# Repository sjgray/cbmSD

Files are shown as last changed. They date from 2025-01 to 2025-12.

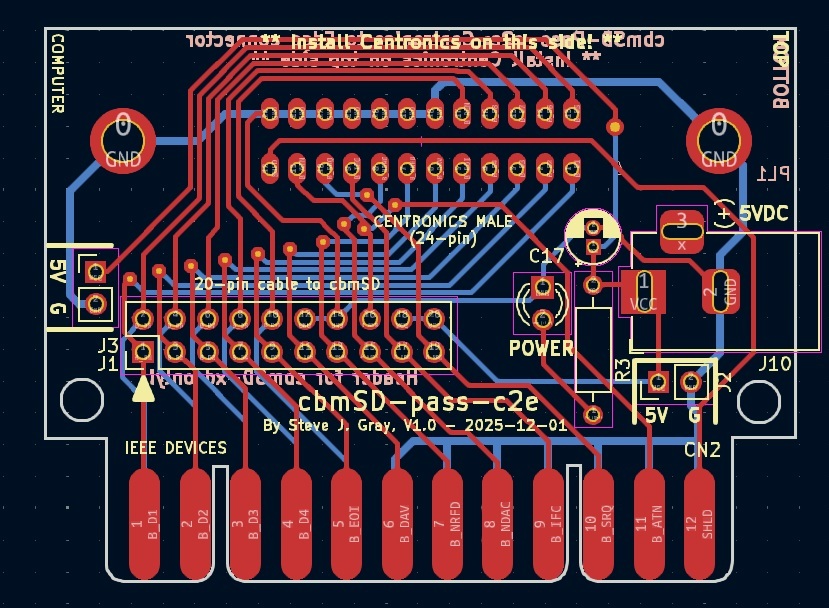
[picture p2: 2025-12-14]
passthru/pass-c2e/Pics/2025-12-01-Routed.jpg

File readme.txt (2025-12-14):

cbmSD family of SD Card Drives for Commodore Computers with IEEE
================================================================

The goal of this project is to create free open-source disk drive
solutions that are easy to build using all thru-hole parts plus
the use of a common inexpensive SD card module.

There are several variations depending on your usage:

1) cbmSD  (In development)
           A full solution providing both IEEE and IEC ports.
           For use on PET/CBM and most Commodore 8-bit machines.
           Direct-plug for IEEE but can connect to IEC devices
           with standard IEC cable.

2) cbmSD-mini
           Direct-plug solutions for PET/CBM machines with IEEE.
           With IEEE pass-thru.

3) cbmSD-xd
           Proprietary cable solution for PET/CBM machines.
           Several Pass-thru boards connect to back of computer, with ribbon cable to SD card board.
           No expensive IEEE cable required.

You will need a simple cassette port power plug or you can
power it with a standard 5V adapter with barrel jack.

Project Page
------------

http://www.cbmsteve.ca/cbmsd/index.html

Status
------

DEVICE     VER   DATE       STATUS

cbmSD      -     -          In development. Requires firmware changes
cbmSD-mini 1.2   2024-02-21 Working
cbmSD-mini 1.2v  2024-07-30 Working. Vertical mounting option.
cbmSD-xd   1.0   2024-11-18 Working. Requires cbmSD-pass board.
pass-e2e   1.0   2024-11-18 Working. Edge-2-Edge
pass-e2c   1.0   1014-11-22 Working. Edge-2-Centronics female
pass-c2e   1.0   2025-12-01 Untested. Centronics-2-Edge

Steve
2025-12-14

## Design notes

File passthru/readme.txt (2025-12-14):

cbmSD-pass - Pass-thru board for cbmSD-xd
=========================================

**NEW** Webpage: http://cbmsteve.ca/cbmsd/index.html

These pass-thru boards plug into the back of the PET/CBM and
connects to power (via cassette port or power adapter).
The "XD" connector combines the power and IEEE signals into one
proprietary pinout for convenient connection to the cbmSD-xd
board using a simple 20-pin ribbon cable. Note: That the IEEE
standard is a 24-pin connector. The GROUND pins have been
consolidated and 5V pins have been added.

You will need a simple cassette port power plug or you can
power it with a standard 5V adapter with barrel jack.

There are three versions available:

1) "E2E" - Edge-2-Edge. Edge connector output. Horizontal or Vertical mount options.
2) "E2C" - Edge-2-Centronics. Centronics female connector as used on devices.
3) "C2E" - Centronics-2-Edge. For SK machines.

Features
--------

- Proprietary 20-pin "cbmSD" header (IEEE + Power).
- Barrel Jack for 5V power.
- Power LED.
- Passthru connector to additional devices.

Status
------

2024-11-10 E2E V1.0 - Verified working as intended.
2024-11-22 E2C V1.0 - Verified working as intended.
2025-12-01 C2E V1.0 - Untested.

Steve
2025-12-14

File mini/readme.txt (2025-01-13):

cbmSD-mini - SD Card Drive for Commodore Computers with IEEE
============================================================

The goal of this project is to create a free open-source
disk drive solution that is easy to build using all
thru-hole parts plus the use of a common inexpensive SD
card module.

This device is based on the petSD+ v2.4 from Nils Eilers.
I have removed all the non-essential features and have
designed it to plug directly into the back of the computer.
No IEEE cables are required. However, it also has a
pass-thru to add additional drives if you need.

You will need a simple cassette port power plug or you can
power it with a standard 5V adapter with barrel jack.

Features
--------

- Direct plug into IEEE port (PET-Edge connector)
- V1.2v has vertical mounting option.
- Pass-thru IEEE PET-Edge connector.
- Power, Busy and Error lights.
- SD module can be mounted on header or extended via wires.
- Reset switch.
- Two Power headers for input or output (to additional
  cbmSD-mini units).
- Mounting holes for future 3D case.

Project Page
------------

http://www.cbmsteve.ca/cbmsd/index.html

Status
------

 cbmSD-mini 1.1:  Removed IEC port and AUX header. IEEE only for PET/CBM users.
                  Gerbers sent to JLCPCB on 2021-05-14.
 cbmSD-mini 1.2:  Fix trace short on LED. Remove 74125 which is not reqired
                  for IEEE. Update design for Kicad7.
                  Gerbers sent to JLCPCB on 2024-02-21.
 cmmSD-mini 1.2v  Add vertical mounting option.
                  Gerbers sent to JLCPCB on 2024-07-30.

Steve
2025-01-13

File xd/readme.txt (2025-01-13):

cbmSD-xd - SD Card Drive for Commodore Computers with IEEE
==========================================================

**NEW** Webpage: http://cbmsteve.ca/cbmsd/index.html

The goal of this project is to create a free open-source
disk drive solution that is easy to build using all
thru-hole parts plus the use of a common inexpensive SD
card module.

This device is based on the petSD+ v2.4 from Nils Eilers.

This is a variant of cbmSD-mini. The "XD" stands for
eXternal Drive (or eXperimental Device as I am not sure
what the ultimate form this might be).

This version comes in two parts:

1) IEEE pass-thru and "cbmSD" connector.
2) cbmSD-xd board

The pass-thru plugs into the back of the PET/CBM and connects
to power (via cassette port or power adapter). The "XD"
connector combines the power and IEEE signals into one
proprietary pinout for convenient connection to the cbmSD-xd
board using a simple 20-pin ribbon cable. Note: That the IEEE
standard is a 24-pin connector. The GROUND pins have been
consolidated and 5V pins have been added.

You will need a simple cassette port power plug or you can
power it with a standard 5V adapter with barrel jack.

Features
--------

- Requires cbmSD-pass board (there are 2 variations)
- Proprietary 20-pin IEEE/Power connector
- Power, Busy and Error lights
- SD module is mounted directly to pcb so it does not mount
  overtop any components
- Reset switch.
- Mounting holes for future 3D case.

Status
------

 V1.0: First release. Verified working as intended.

Steve
2025-01-13

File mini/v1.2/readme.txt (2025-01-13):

cbmSD-mini - SD Card Drive for Commodore Computers with IEEE
============================================================

Webpage: http://www.6502.org/users/sjgray/projects/cbmsd/index.html

The goal of this project is to create a free open-source
disk drive solution that is easy to build using all
thru-hole parts plus the use of a common inexpensive SD
card module.

This device is based on the petSD+ v2.4 from Nils Eilers.
I have removed all the non-essential features and have
designed it to plug directly into the back of the computer.
No IEEE cables are required. However, it also has a
pass-thru to add additional drives if you need.

You will need a simple cassette port power plug or you can
power it with a standard 5V adapter with barrel jack.

Features
--------

- Direct plug into IEEE port
- Pass-thru IEEE port
- Power, Busy and Error lights
- SD module can be mounted on header or extended via wires.
- Reset switch.
- Two Power headers for input or output (to additional
  cbmSD-mini units.
- Mounting holes for future 3D case.

Status
------

 V1.0: Was the first version for prototyping. It had a few errors.       

 V1.1: Removed IEC port and AUX header. IEEE only for PET/CBM users.
       Gerbers sent to JLCPCB on 2021-05-14.
       Board built and verified working with one small fix.

 V1.2: Fix trace short on LED. Remove 74125 which is not reqired
       for IEEE. Update design for Kicad7.
       Gerbers sent to JLCPCB on 2024-02-21.
       Board built and verified working 2024-03-17

Steve
2024-03-18

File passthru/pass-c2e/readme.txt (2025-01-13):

cbmSD-pass - IEEE passthru for remote cbmSD Drive
=================================================

**NEW** Webpage: http://cbmsteve.ca/cbmsd/index.html

The goal of this project is to create a free open-source
disk drive solution that is easy to build using all
thru-hole parts plus the use of a common inexpensive SD
card module.

This is an IEEE pass-thru and connection to remote
cbmSD device and to allow normal IEEE devices to be
chained to the PET computer.

Status
------

 V1.0: First cbmSD-pass board

Steve
2024-11-16

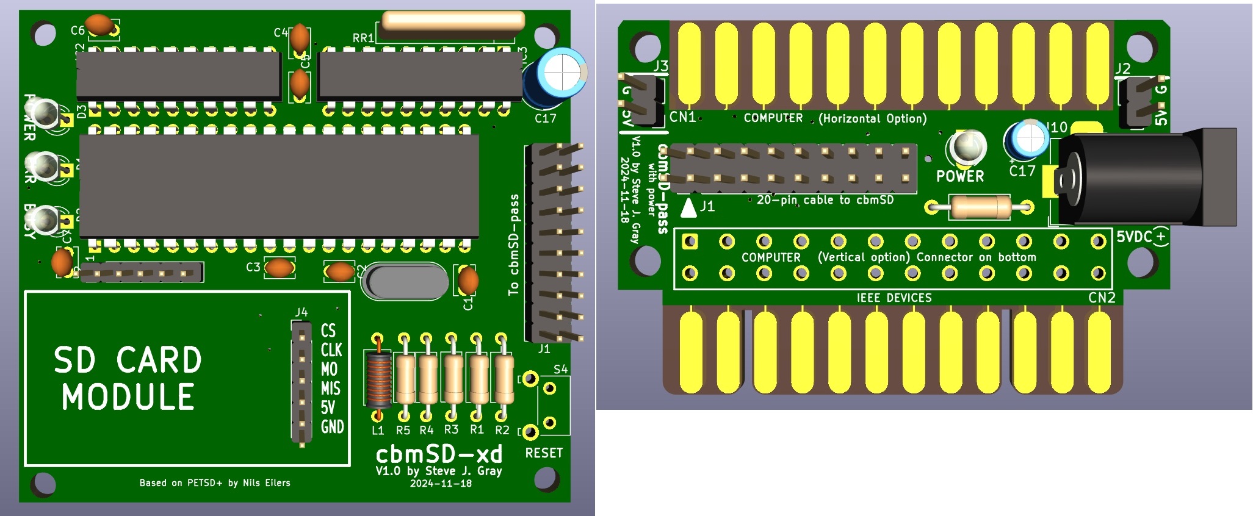
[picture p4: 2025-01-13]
xd/v1/Pics/cbmSD-xd with passthru render.jpg

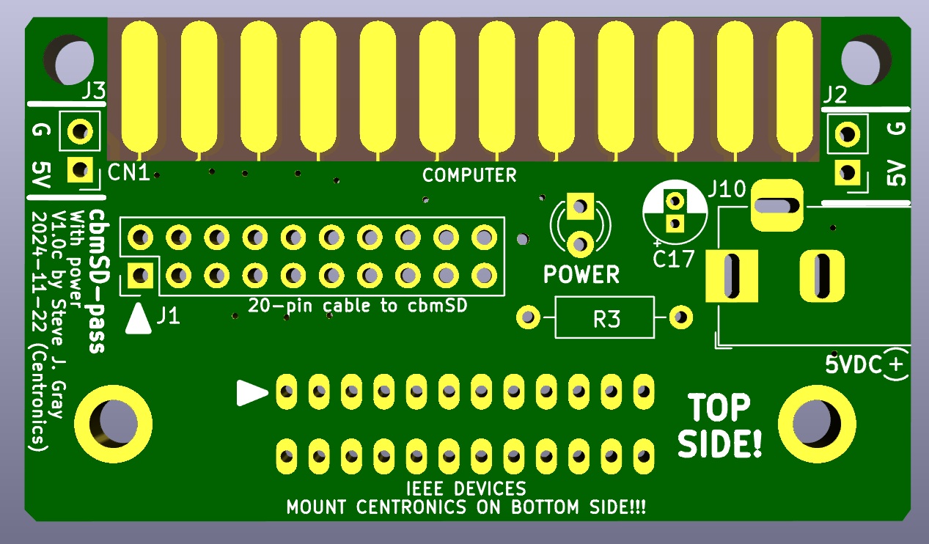
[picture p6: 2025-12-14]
passthru/pass-e2c/Pics/cbmSD-pass-render.jpg

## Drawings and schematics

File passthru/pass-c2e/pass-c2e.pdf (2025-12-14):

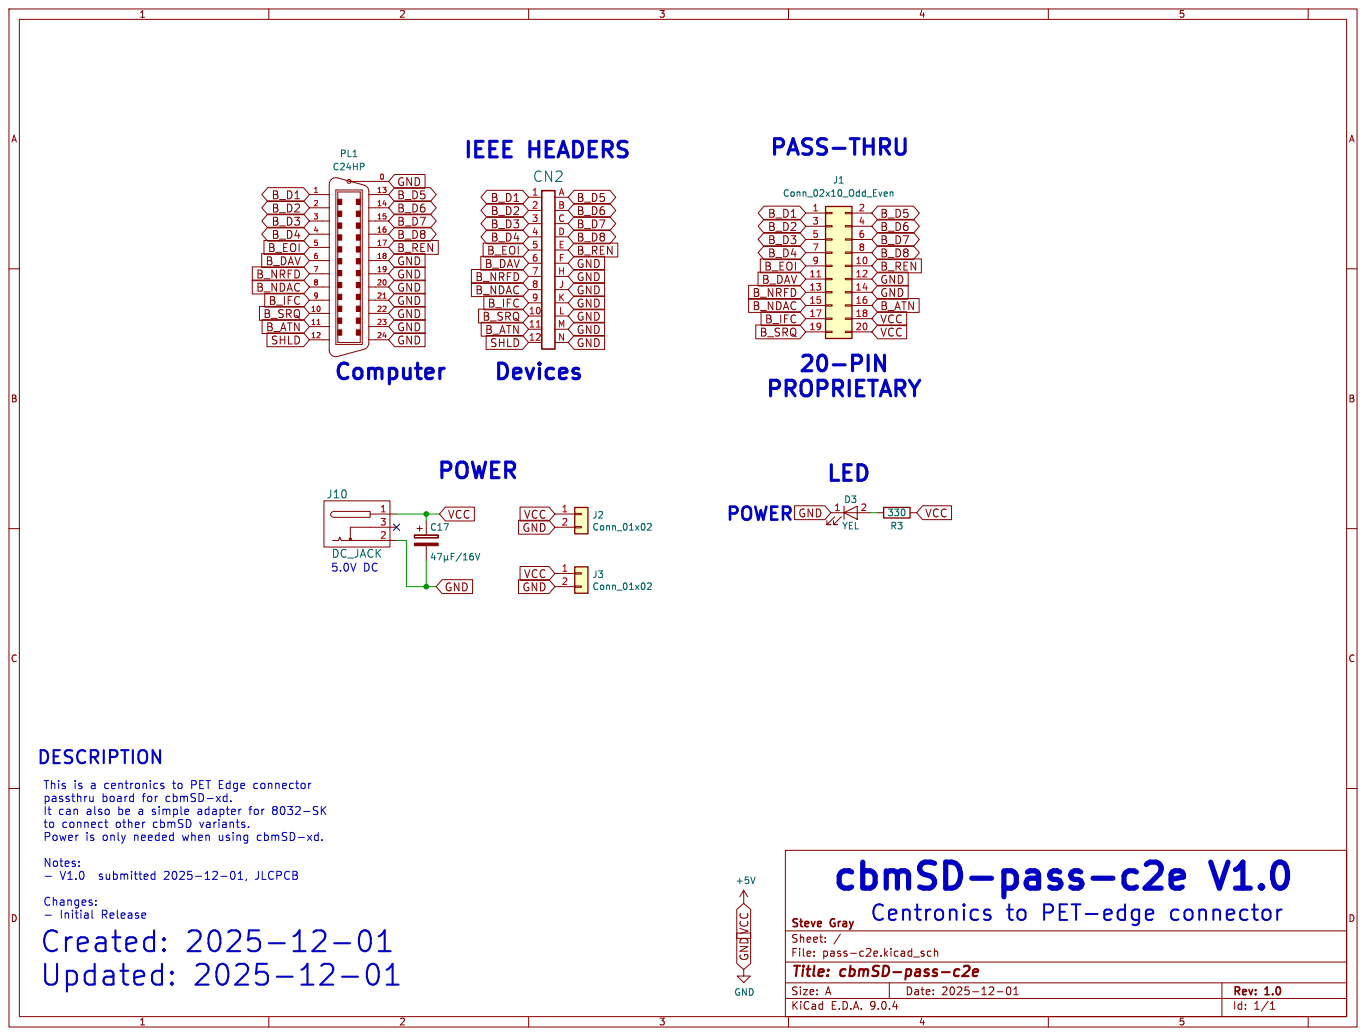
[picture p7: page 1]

It can also be a simple adapter for 8032-SK

File: pass-c2e.kicad_sch Sheet: / Steve Gray

Id: 1/1 Title: cbmSD-pass-c2e

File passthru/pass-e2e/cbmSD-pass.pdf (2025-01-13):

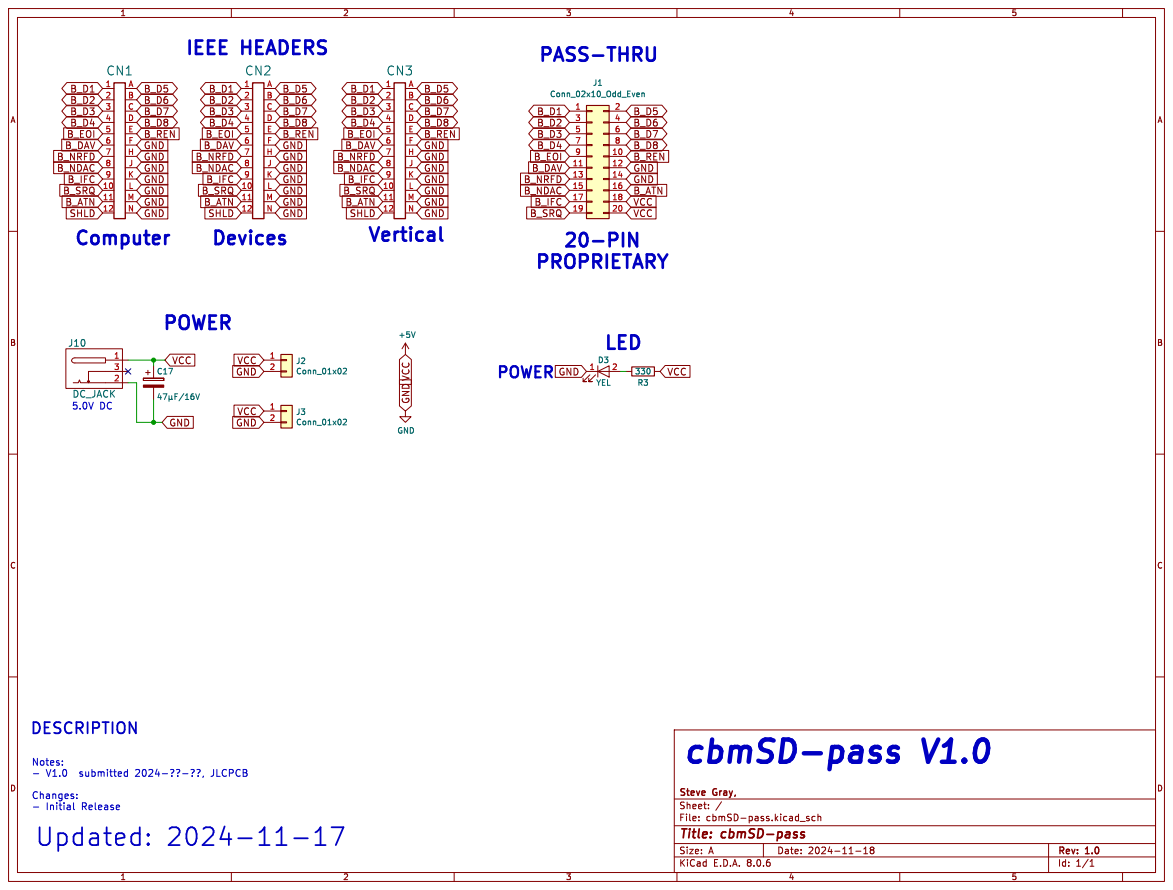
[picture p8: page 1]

Changes: - Initial Release Updated: 2024-11-17

File: cbmSD-pass.kicad_sch Sheet: / Steve Gray,

Id: 1/1 Title: cbmSD-pass

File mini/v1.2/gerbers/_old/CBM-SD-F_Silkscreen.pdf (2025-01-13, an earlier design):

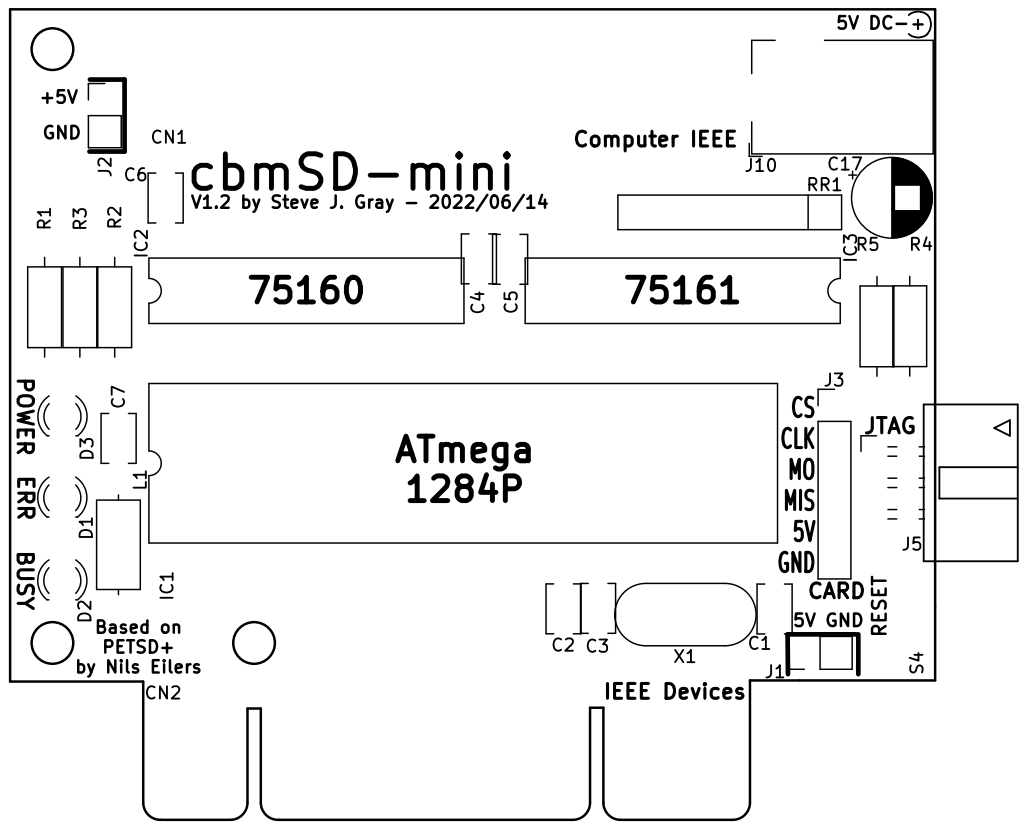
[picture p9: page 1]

V1.2 by Steve J. Gray - 2022/06/14 cbmSD-mini BUSY

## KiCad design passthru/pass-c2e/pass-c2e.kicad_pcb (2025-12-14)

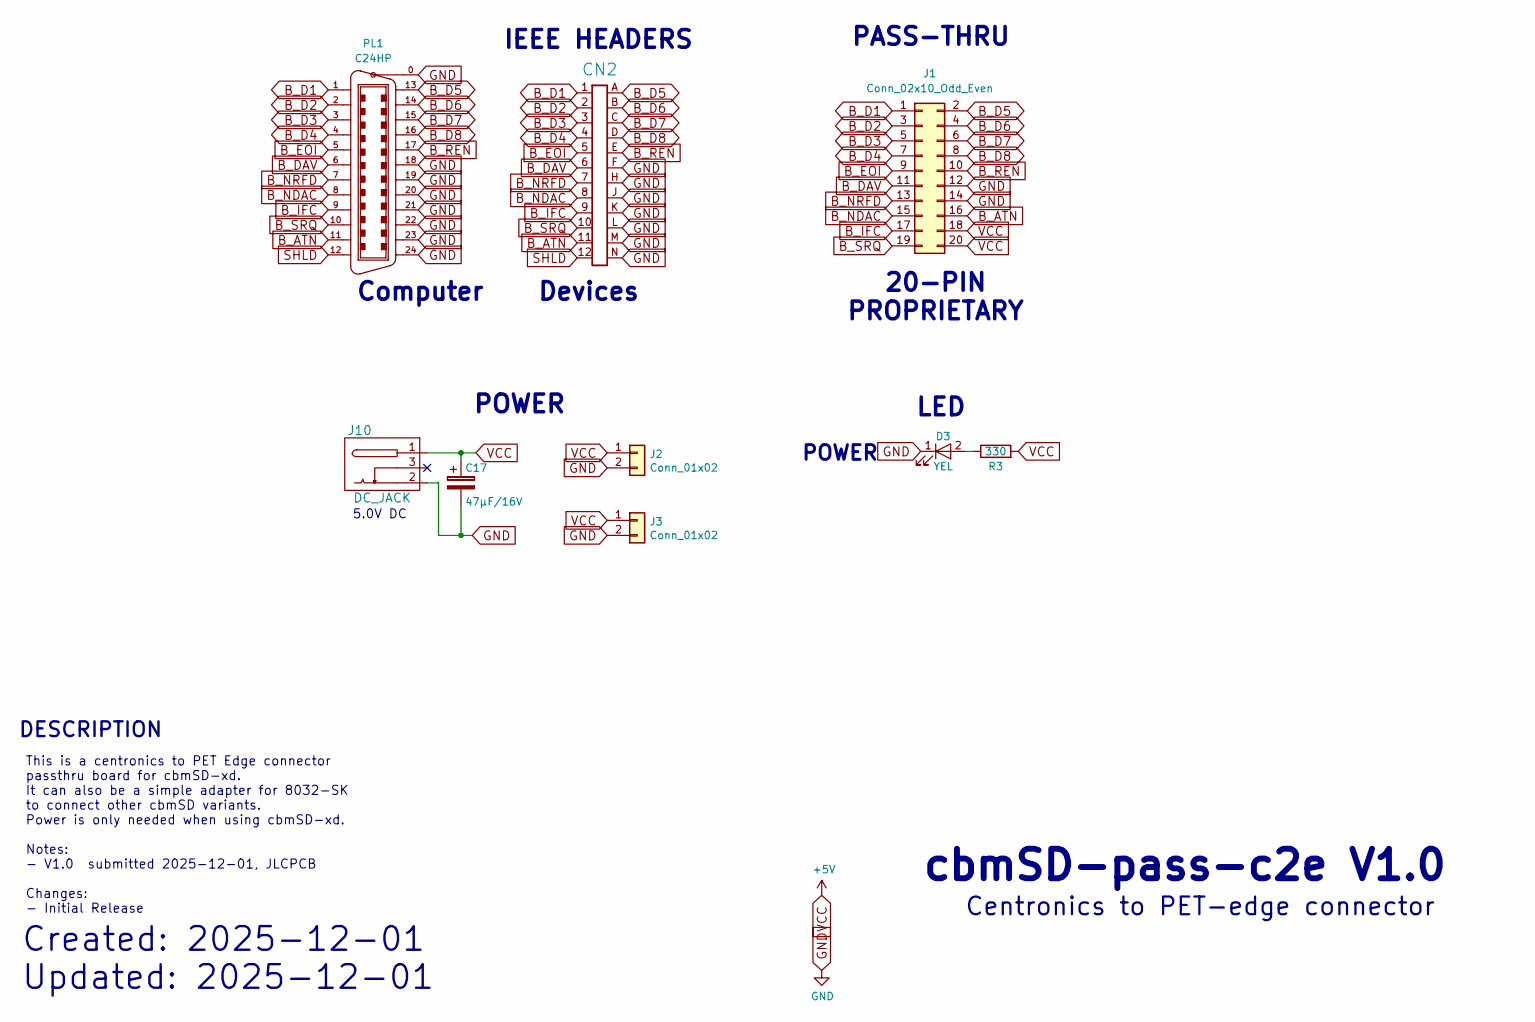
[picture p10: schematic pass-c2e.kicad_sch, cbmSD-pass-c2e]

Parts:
C17: 47µF/16V; CP_Radial_D4.0mm_P1.50mm
CN2: EDGE_CON_02x12; EDGE_CON_24P
D3: YEL; LED_D3.0mm_Clear
J1: Conn_02x10_Odd_Even; PinHeader_2x10_P2.54mm_Vertical
J2, J3: Conn_01x02; PinHeader_1x02_P2.54mm_Vertical
J10: DC_JACK; BarrelJack_Horizontal
PL1: C24HP; con-amp-champ-24HP
R3: 330; R_Axial_DIN0207_L6.3mm_D2.5mm_P10.16mm_Horizontal

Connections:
B_ATN: CN2.11, J1.16, PL1.11
B_D1: CN2.1, J1.1, PL1.1
B_D2: CN2.2, J1.3, PL1.2
B_D3: CN2.3, J1.5, PL1.3
B_D4: CN2.4, J1.7, PL1.4
B_D5: CN2.A, J1.2, PL1.13
B_D6: CN2.B, J1.4, PL1.14
B_D7: CN2.C, J1.6, PL1.15
B_D8: CN2.D, J1.8, PL1.16
B_DAV: CN2.6, J1.11, PL1.6
B_EOI: CN2.5, J1.9, PL1.5
B_IFC: CN2.9, J1.17, PL1.9
B_NDAC: CN2.8, J1.15, PL1.8
B_NRFD: CN2.7, J1.13, PL1.7
B_REN: CN2.E, J1.10, PL1.17
B_SRQ: CN2.10, J1.19, PL1.10
GND: C17.2, CN2.F, CN2.H, CN2.J, CN2.K, CN2.L, CN2.M, CN2.N, D3.1 (K), J1.12, J1.14, J2.2, J3.2, J10.2, PL1.0, PL1.18, PL1.19, PL1.20, PL1.21, PL1.22, PL1.23, PL1.24
unnamed: D3.2 (A), R3.1
SHLD: CN2.12, PL1.12
VCC: C17.1, J1.18, J1.20, J2.1, J3.1, J10.1, R3.2

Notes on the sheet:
5.0V DC
Computer
Centronics to PET-edge connector
This is a centronics to PET Edge connector passthru board for cbmSD-xd. It can also be a simple adapter for 8032-SK to connect other cbmSD variants. Power is only needed when using cbmSD-xd. Notes: - V1.0 submitted 2025-12-01, JLCPCB Changes: - Initial Release
DESCRIPTION
Devices
cbmSD-pass-c2e V1.0
PASS-THRU
IEEE HEADERS
POWER
20-PIN PROPRIETARY
LED
Created: 2025-12-01 Updated: 2025-12-01

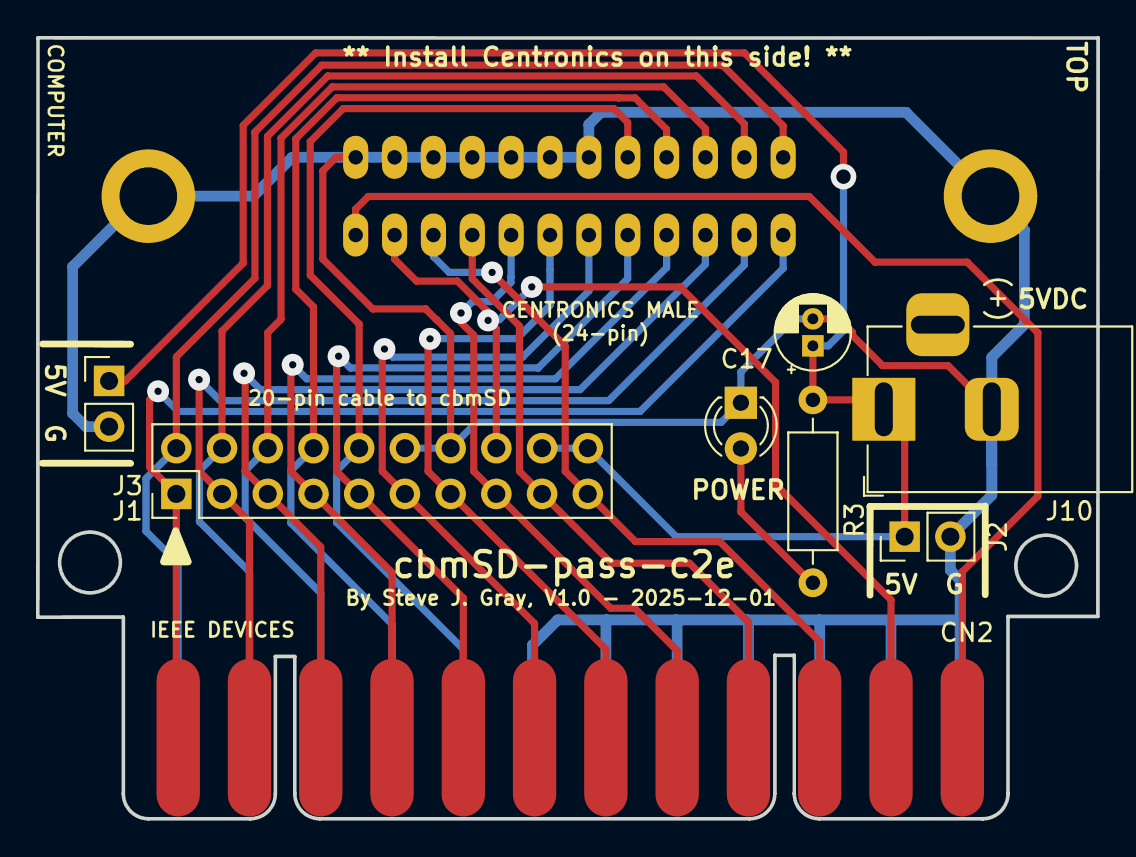
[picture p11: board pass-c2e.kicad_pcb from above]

Board: 2 copper layers, 58.9 x 43.4 mm, 9 parts (1 on the bottom side), 20 nets.

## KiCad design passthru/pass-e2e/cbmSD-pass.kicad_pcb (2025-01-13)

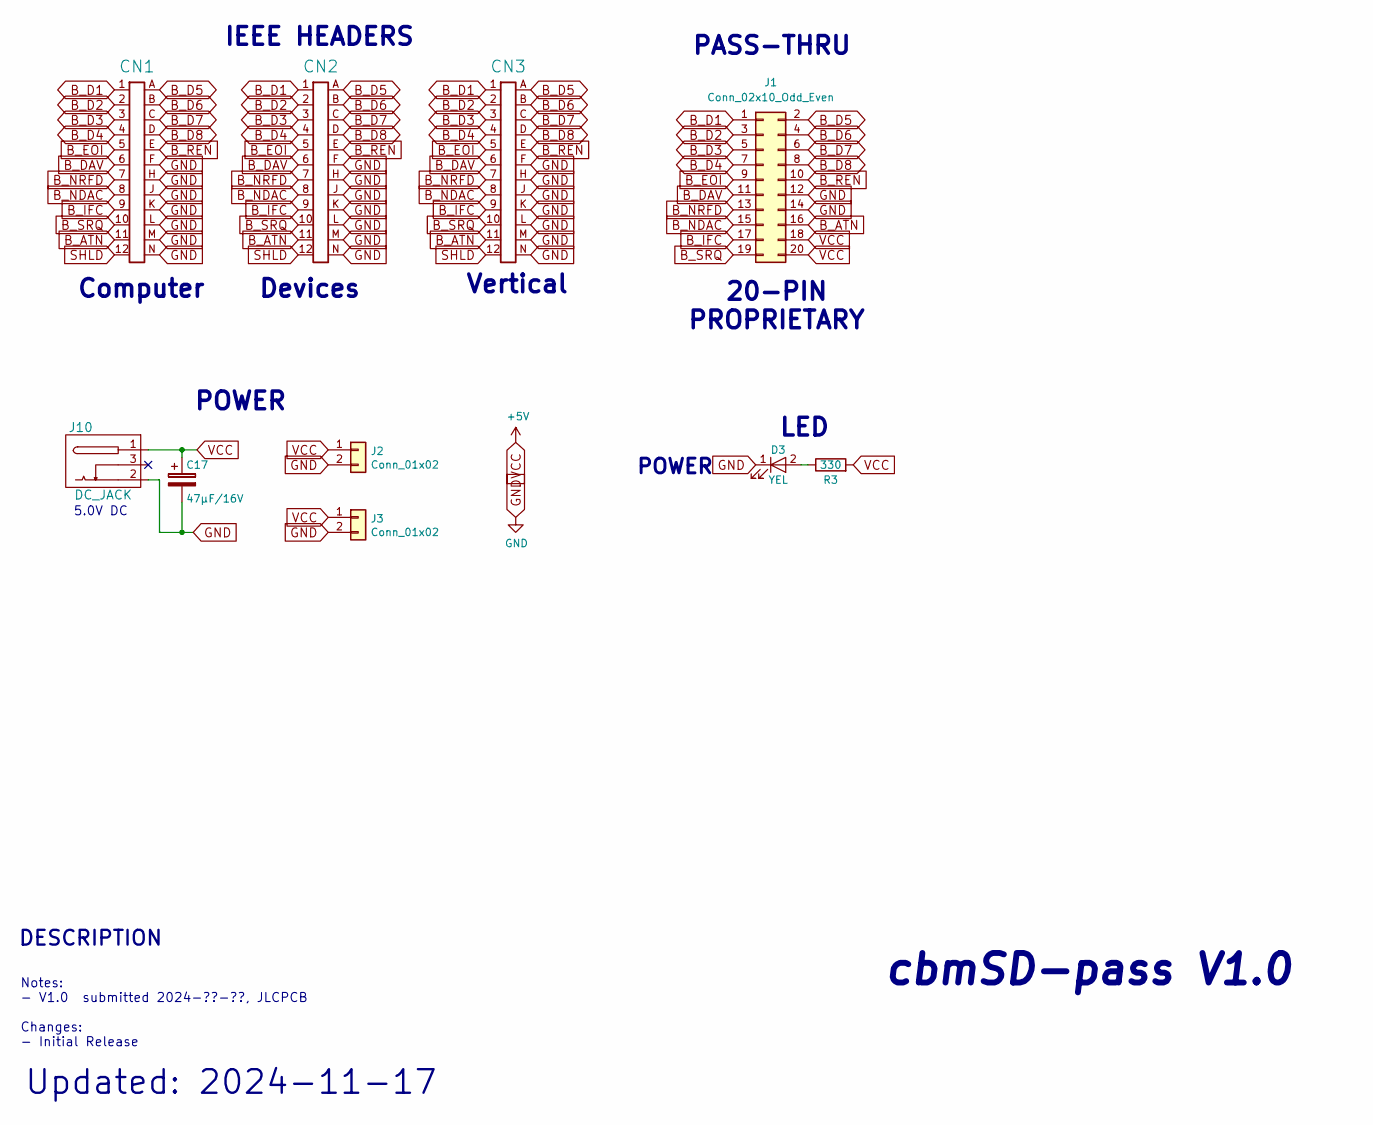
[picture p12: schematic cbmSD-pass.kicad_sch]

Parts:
C17: 47µF/16V; CP_Radial_D4.0mm_P1.50mm
CN1, CN2: EDGE_CON_02x12; EDGE_CON_24P
CN3: EDGE_CON_02x12; EDGE_02x12-VERTICAL_THT
D3: YEL; LED_D3.0mm_Clear
J1: Conn_02x10_Odd_Even; PinHeader_2x10_P2.54mm_Vertical
J2, J3: Conn_01x02; PinHeader_1x02_P2.54mm_Vertical
J10: DC_JACK; BarrelJack_Horizontal
R3: 330; R_Axial_DIN0207_L6.3mm_D2.5mm_P10.16mm_Horizontal

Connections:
B_ATN: CN1.11, CN2.11, CN3.11, J1.16
B_D1: CN1.1, CN2.1, CN3.1, J1.1
B_D2: CN1.2, CN2.2, CN3.2, J1.3
B_D3: CN1.3, CN2.3, CN3.3, J1.5
B_D4: CN1.4, CN2.4, CN3.4, J1.7
B_D5: CN1.A, CN2.A, CN3.A, J1.2
B_D6: CN1.B, CN2.B, CN3.B, J1.4
B_D7: CN1.C, CN2.C, CN3.C, J1.6
B_D8: CN1.D, CN2.D, CN3.D, J1.8
B_DAV: CN1.6, CN2.6, CN3.6, J1.11
B_EOI: CN1.5, CN2.5, CN3.5, J1.9
B_IFC: CN1.9, CN2.9, CN3.9, J1.17
B_NDAC: CN1.8, CN2.8, CN3.8, J1.15
B_NRFD: CN1.7, CN2.7, CN3.7, J1.13
B_REN: CN1.E, CN2.E, CN3.E, J1.10
B_SRQ: CN1.10, CN2.10, CN3.10, J1.19
GND: C17.2, CN1.F, CN1.H, CN1.J, CN1.K, CN1.L, CN1.M, CN1.N, CN2.F, CN2.H, CN2.J, CN2.K, CN2.L, CN2.M, CN2.N, CN3.F, CN3.H, CN3.J, CN3.K, CN3.L, CN3.M, CN3.N, D3.1 (K), J1.12, J1.14, J2.2, J3.2, J10.2
unnamed: D3.2 (A), R3.1
SHLD: CN1.12, CN2.12, CN3.12
VCC: C17.1, J1.18, J1.20, J2.1, J3.1, J10.1, R3.2

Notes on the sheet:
5.0V DC
Computer
Notes: - V1.0 submitted 2024-??-??, JLCPCB Changes: - Initial Release
Vertical
DESCRIPTION
Devices
cbmSD-pass V1.0
PASS-THRU
IEEE HEADERS
POWER
20-PIN PROPRIETARY
LED
Updated: 2024-11-17

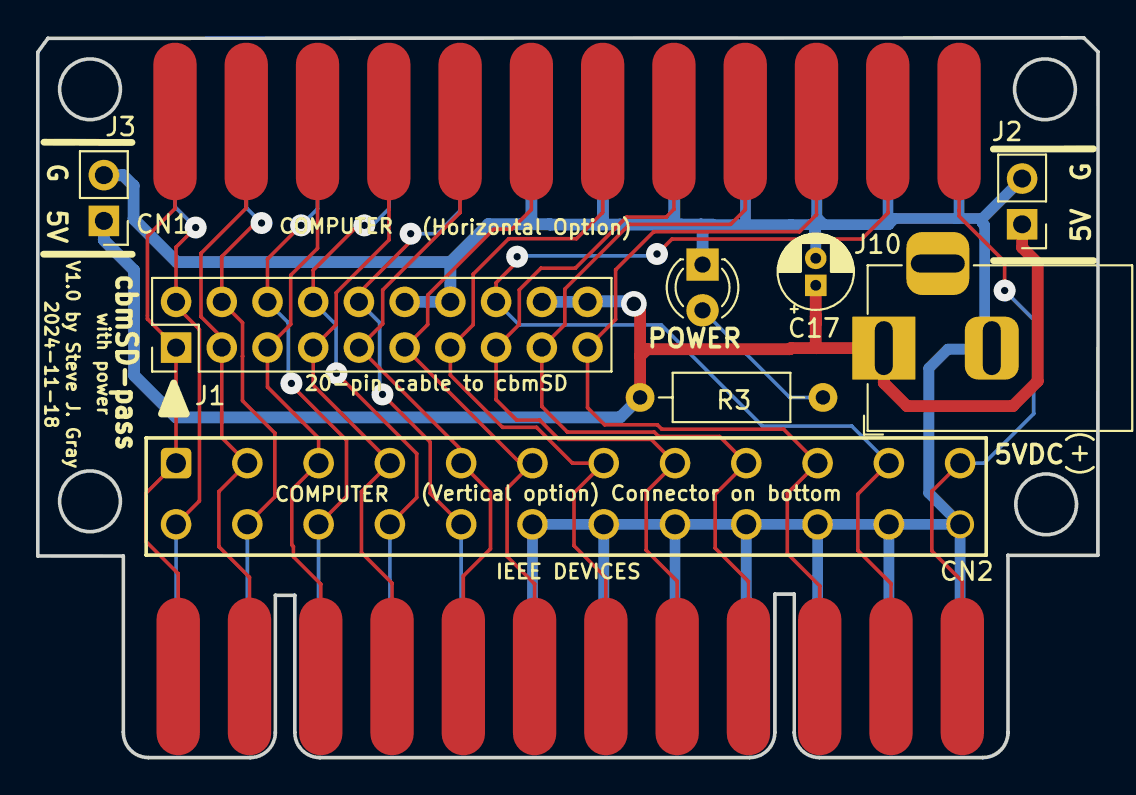
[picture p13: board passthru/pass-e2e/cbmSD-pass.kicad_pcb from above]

Board: 2 copper layers, 58.9 x 40.0 mm, 10 parts (1 on the bottom side), 20 nets.

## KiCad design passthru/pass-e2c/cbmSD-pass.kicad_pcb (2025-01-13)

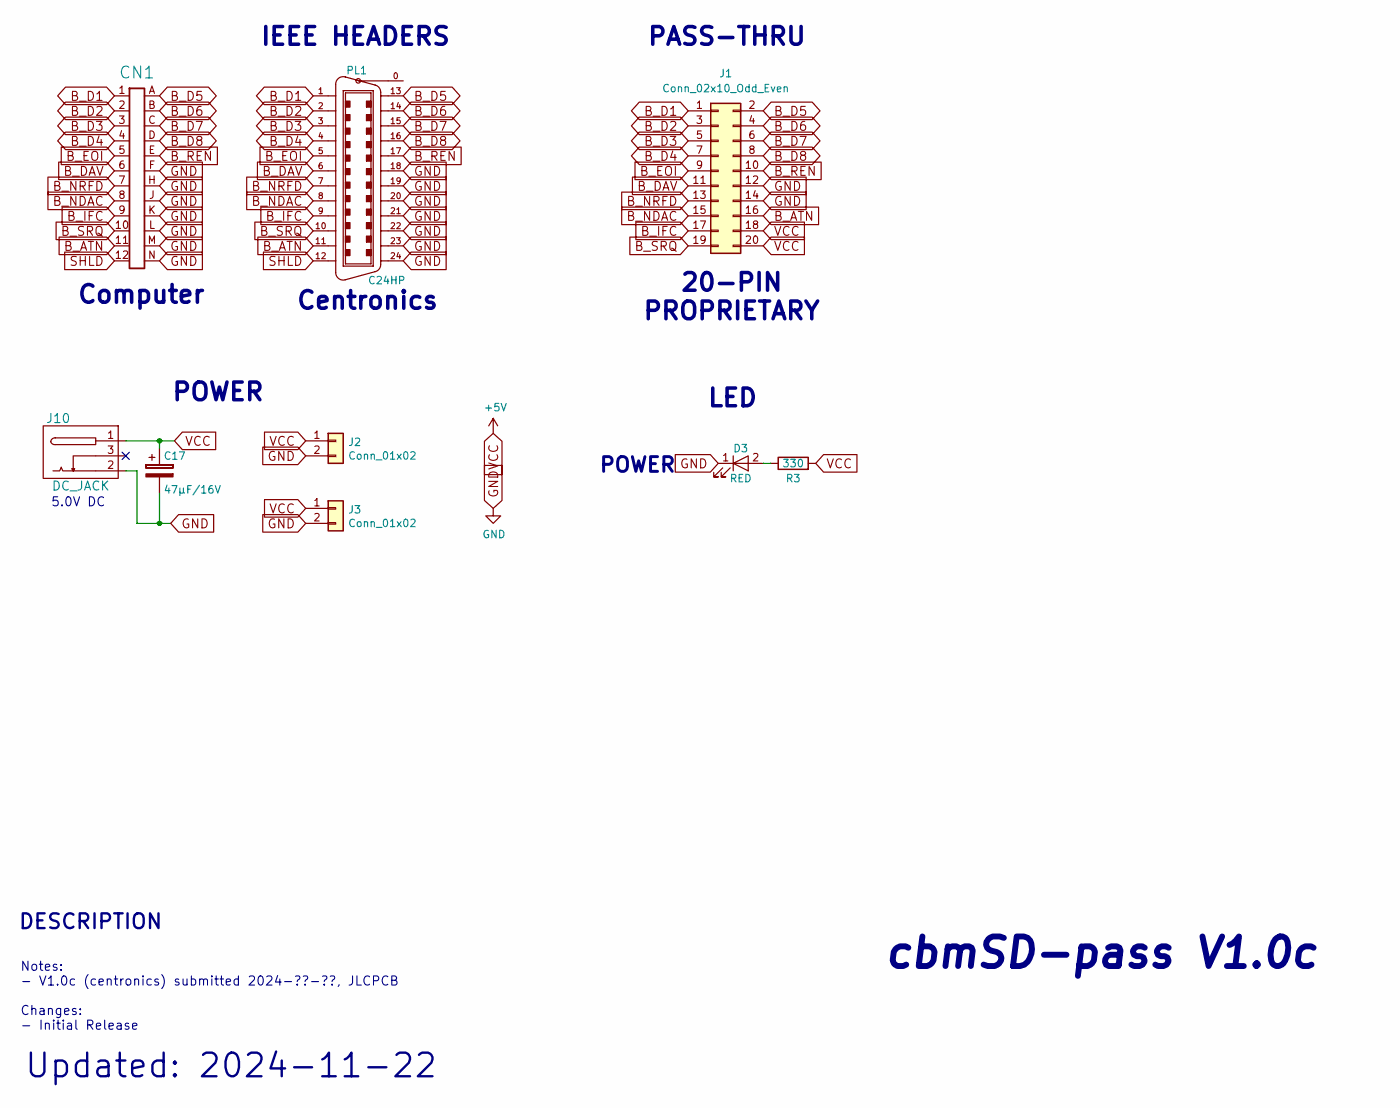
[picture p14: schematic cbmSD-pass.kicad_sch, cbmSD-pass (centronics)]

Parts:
C17: 47µF/16V; CP_Radial_D4.0mm_P1.50mm
CN1: EDGE_CON_02x12; EDGE_CON_24P
D3: RED; LED_D3.0mm_Clear
J1: Conn_02x10_Odd_Even; PinHeader_2x10_P2.54mm_Vertical
J2, J3: Conn_01x02; PinHeader_1x02_P2.54mm_Vertical
J10: DC_JACK; BarrelJack_Horizontal
PL1: C24HP; con-amp-champ-24HP
R3: 330; R_Axial_DIN0207_L6.3mm_D2.5mm_P10.16mm_Horizontal

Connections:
B_ATN: CN1.11, J1.16, PL1.11
B_D1: CN1.1, J1.1, PL1.1
B_D2: CN1.2, J1.3, PL1.2
B_D3: CN1.3, J1.5, PL1.3
B_D4: CN1.4, J1.7, PL1.4
B_D5: CN1.A, J1.2, PL1.13
B_D6: CN1.B, J1.4, PL1.14
B_D7: CN1.C, J1.6, PL1.15
B_D8: CN1.D, J1.8, PL1.16
B_DAV: CN1.6, J1.11, PL1.6
B_EOI: CN1.5, J1.9, PL1.5
B_IFC: CN1.9, J1.17, PL1.9
B_NDAC: CN1.8, J1.15, PL1.8
B_NRFD: CN1.7, J1.13, PL1.7
B_REN: CN1.E, J1.10, PL1.17
B_SRQ: CN1.10, J1.19, PL1.10
GND: C17.2, CN1.F, CN1.H, CN1.J, CN1.K, CN1.L, CN1.M, CN1.N, D3.1 (K), J1.12, J1.14, J2.2, J3.2, J10.2, PL1.18, PL1.19, PL1.20, PL1.21, PL1.22, PL1.23, PL1.24
unnamed: D3.2 (A), R3.1
SHLD: CN1.12, PL1.12
VCC: C17.1, J1.18, J1.20, J2.1, J3.1, J10.1, R3.2

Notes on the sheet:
5.0V DC
Computer
Notes: - V1.0c (centronics) submitted 2024-??-??, JLCPCB Changes: - Initial Release
DESCRIPTION
cbmSD-pass V1.0c
Centronics
PASS-THRU
IEEE HEADERS
POWER
20-PIN PROPRIETARY
LED
Updated: 2024-11-22

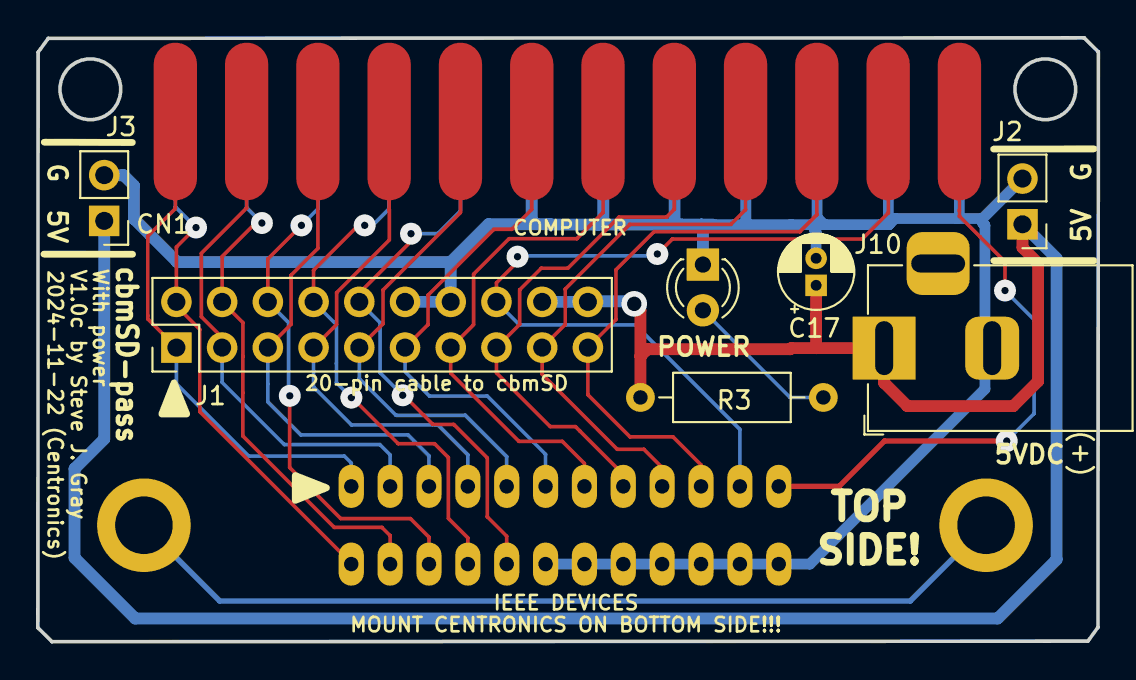
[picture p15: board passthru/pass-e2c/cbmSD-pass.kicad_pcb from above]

Board: 2 copper layers, 58.9 x 33.5 mm, 9 parts (1 on the bottom side), 20 nets.

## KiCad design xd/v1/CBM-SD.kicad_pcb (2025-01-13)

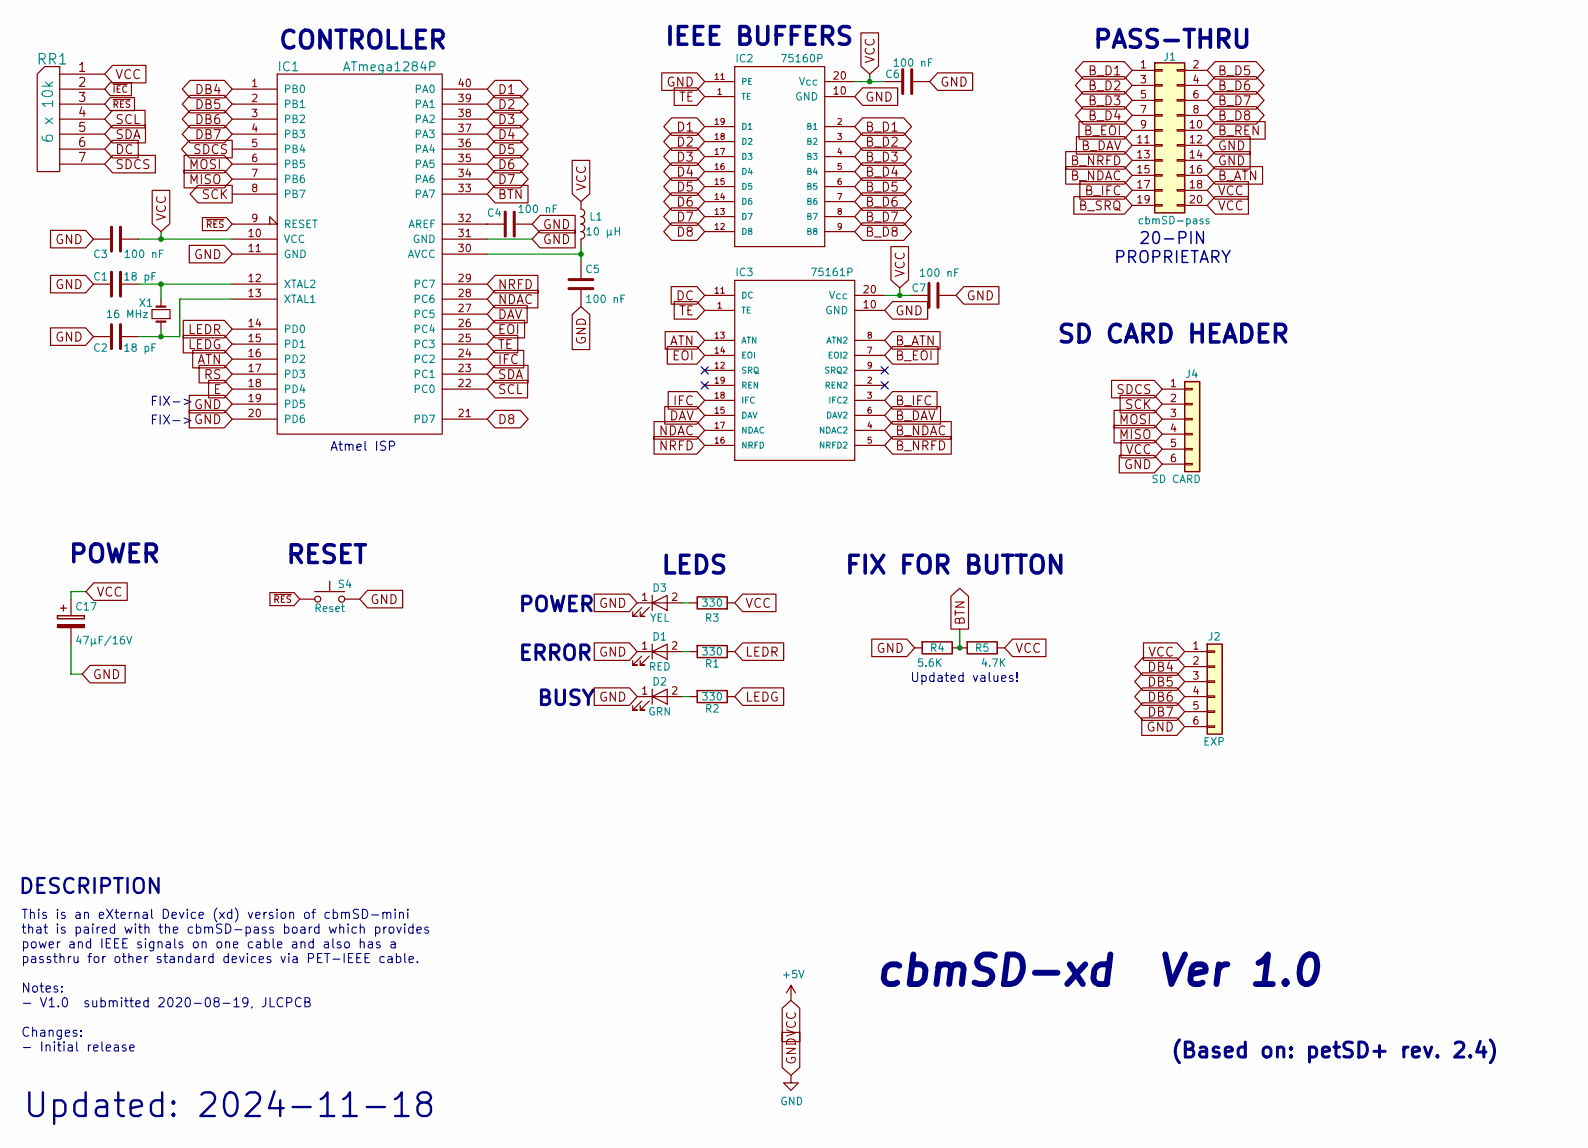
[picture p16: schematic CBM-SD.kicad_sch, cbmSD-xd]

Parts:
C1, C2: 18 pF; C_Disc_D3.8mm_W2.6mm_P2.50mm
C3, C4, C5, C6, C7: 100 nF; C_Disc_D3.8mm_W2.6mm_P2.50mm
C17: 47µF/16V; CP_Radial_D6.3mm_P2.50mm
D1: RED; LED_D3.0mm_Clear
D2: GRN; LED_D3.0mm_Clear
D3: YEL; LED_D3.0mm_Clear
IC1: ATmega1284P; DIP-40_W15.24mm
IC2: 75160P; DIP-20_W7.62mm
IC3: 75161P; DIP-20_W7.62mm
J1: cbmSD-pass; PinHeader_2x10_P2.54mm_Vertical
J2: EXP; PinHeader_1x06_P2.54mm_Vertical
J4: SD CARD; PinHeader_1x06_P2.54mm_Vertical
L1: 10 µH; L_Axial_L7.0mm_D3.3mm_P10.16mm_Horizontal_Fastron_MICC
R1, R2, R3: 330; R_Axial_DIN0207_L6.3mm_D2.5mm_P10.16mm_Horizontal
R4: 5.6K; R_Axial_DIN0207_L6.3mm_D2.5mm_P10.16mm_Horizontal
R5: 4.7K; R_Axial_DIN0207_L6.3mm_D2.5mm_P10.16mm_Horizontal
RR1: 6 x 10k; R_Array_SIP7
S4: Reset; SW_Tactile_SKHH_Angled
X1: 16 MHz; Crystal_HC49-4H_Vertical

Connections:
ATN: IC1.16 (PD2), IC3.13 (ATN)
BTN: IC1.33 (PA7), R4.1, R5.2
B_ATN: IC3.8 (ATN2), J1.16
B_D1: IC2.2 (B1), J1.1
B_D2: IC2.3 (B2), J1.3
B_D3: IC2.4 (B3), J1.5
B_D4: IC2.5 (B4), J1.7
B_D5: IC2.6 (B5), J1.2
B_D6: IC2.7 (B6), J1.4
B_D7: IC2.8 (B7), J1.6
B_D8: IC2.9 (B8), J1.8
B_DAV: IC3.6 (DAV2), J1.11
B_EOI: IC3.7 (EOI2), J1.9
B_IFC: IC3.3 (IFC2), J1.17
B_NDAC: IC3.4 (NDAC2), J1.15
B_NRFD: IC3.5 (NRFD2), J1.13
B_REN: J1.10
B_SRQ: J1.19
D1: IC1.40 (PA0), IC2.19 (D1)
D2: IC1.39 (PA1), IC2.18 (D2)
D3: IC1.38 (PA2), IC2.17 (D3)
D4: IC1.37 (PA3), IC2.16 (D4)
D5: IC1.36 (PA4), IC2.15 (D5)
D6: IC1.35 (PA5), IC2.14 (D6)
D7: IC1.34 (PA6), IC2.13 (D7)
D8: IC1.21 (PD7), IC2.12 (D8)
DAV: IC1.27 (PC5), IC3.15 (DAV)
DB4: IC1.1 (PB0), J2.2
DB5: IC1.2 (PB1), J2.3
DB6: IC1.3 (PB2), J2.4
DB7: IC1.4 (PB3), J2.5
DC: IC3.11 (DC), RR1.6
E: IC1.18 (PD4)
EOI: IC1.26 (PC4), IC3.14 (EOI)
GND: C1.1, C2.1, C3.1, C4.2, C5.2, C6.1, C7.1, C17.2, D1.1 (K), D2.1 (K), D3.1 (K), IC1.11 (GND), IC1.19 (PD5), IC1.20 (PD6), IC1.31 (GND), IC2.10 (GND), IC2.11 (PE), IC3.10 (GND), J1.12, J1.14, J2.6, J4.6, R4.2, S4.2
IFC: IC1.24 (PC2), IC3.18 (IFC)
LEDG: IC1.15 (PD1), R2.1
LEDR: IC1.14 (PD0), R1.1
MISO: IC1.7 (PB6), J4.4
MOSI: IC1.6 (PB5), J4.3
NDAC: IC1.28 (PC6), IC3.17 (NDAC)
NRFD: IC1.29 (PC7), IC3.16 (NRFD)
unnamed: D1.2 (A), R1.2
unnamed: D2.2 (A), R2.2
unnamed: D3.2 (A), R3.1
unnamed: C4.1, IC1.32 (AREF)
unnamed: C5.1, IC1.30 (AVCC), L1.2
unnamed: C2.2, IC1.13 (XTAL1), X1.1
unnamed: C1.2, IC1.12 (XTAL2), X1.2
RS: IC1.17 (PD3)
SCK: IC1.8 (PB7), J4.2
SCL: IC1.22 (PC0), RR1.4
SDA: IC1.23 (PC1), RR1.5
SDCS: IC1.5 (PB4), J4.1, RR1.7
TE: IC1.25 (PC3), IC2.1 (TE), IC3.1 (TE)
VCC: C3.2, C6.2, C7.2, C17.1, IC1.10 (VCC), IC2.20 (Vcc), IC3.20 (Vcc), J1.18, J1.20, J2.1, J4.5, L1.1, R3.2, R5.1, RR1.1 (COM)
~IEC: RR1.2
~RES: IC1.9 (RESET), RR1.3, S4.1

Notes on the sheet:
Updated values!
BUSY
This is an eXternal Device (xd) version of cbmSD-mini that is paired with the cbmSD-pass board which provides power and IEEE signals on one cable and also has a passthru for other standard devices via PET-IEEE cable. Notes: - V1.0 submitted 2020-08-19, JLCPCB Changes: - Initial release
PASS-THRU
20-PIN PROPRIETARY
Atmel ISP
DESCRIPTION
FIX FOR BUTTON
SD CARD HEADER
cbmSD-xd Ver 1.0
CONTROLLER
(Based on: petSD+ rev. 2.4)
FIX->
POWER
RESET
LEDS
ERROR
Updated: 2024-11-18
IEEE BUFFERS

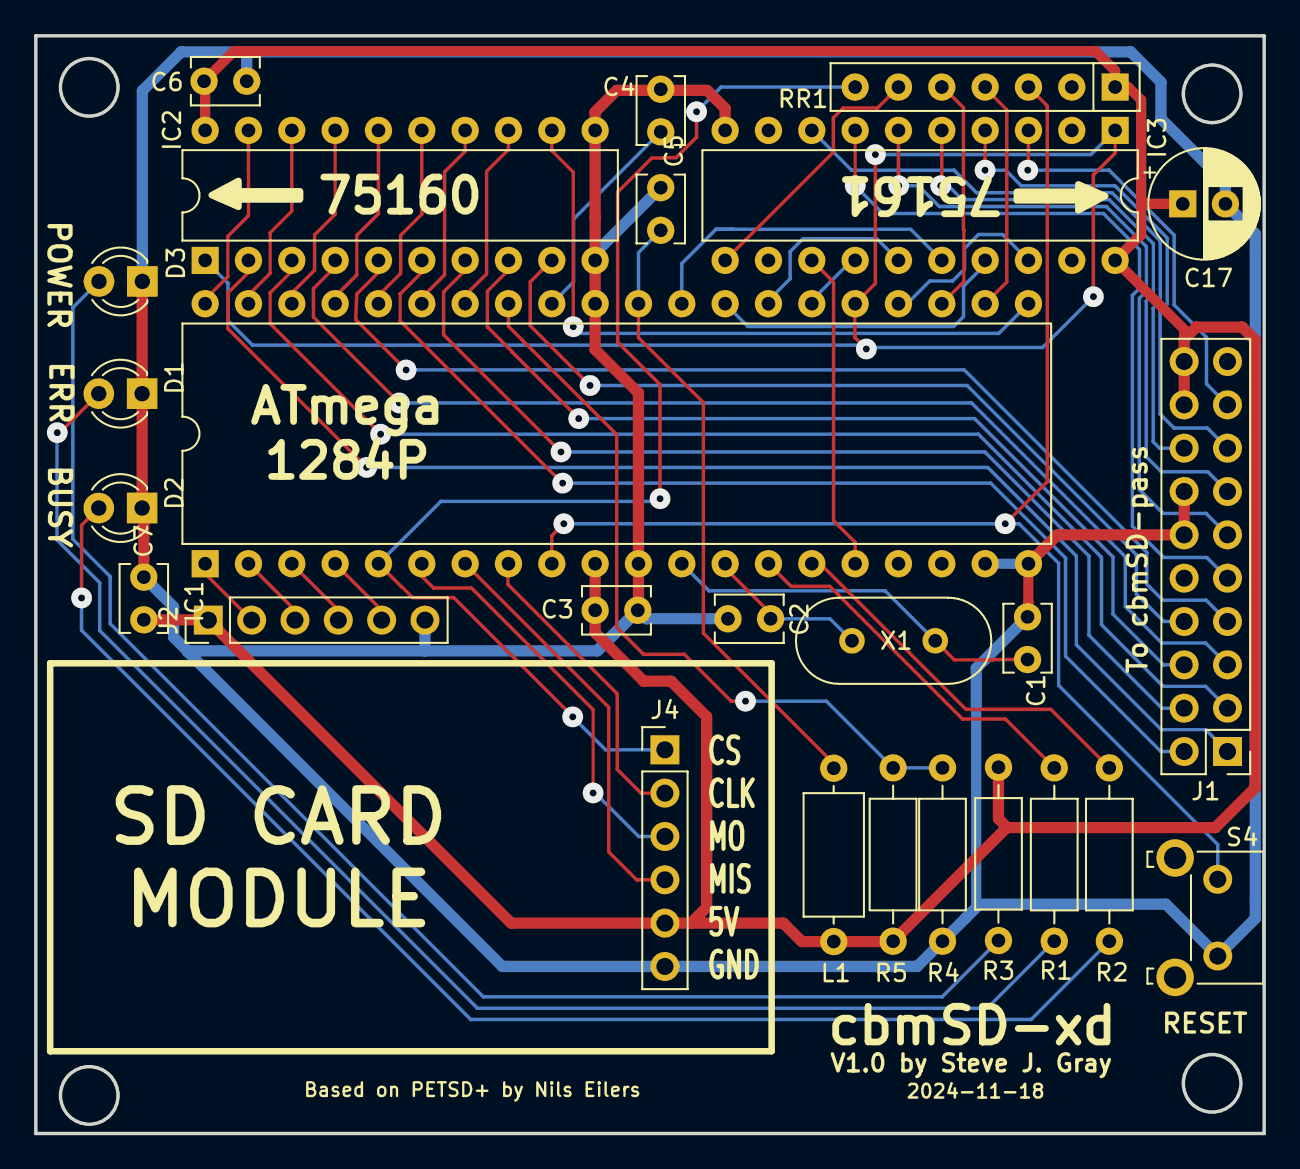
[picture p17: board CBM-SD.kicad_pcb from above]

Board: 2 copper layers, 72.0 x 64.3 mm, 26 parts (0 on the bottom side), 53 nets.

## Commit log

2025-01-13 Re-name and Re-Org. Add cbmSD-xd.
    Rename repository to "cbmSD" and Re-structure directories to reflect "family" of devices. Add cbmSD-xd v1.0 and cbmSD-pass V1.0 boards. Updated readme files for all.
    [CBM-SD-B_Cu.gbr, CBM-SD-B_Mask.gbr, CBM-SD-B_Silkscreen.gbr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]
2025-12-14 Add C2E passthru for SK machines
    Add C2E. Re-org folder names. Update readmes
    [cbmSD-pass-B_Cu.gbr, cbmSD-pass-B_Mask.gbr, cbmSD-pass-B_Silkscreen.gbr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]

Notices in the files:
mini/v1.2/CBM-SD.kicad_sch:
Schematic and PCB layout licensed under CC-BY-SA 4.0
